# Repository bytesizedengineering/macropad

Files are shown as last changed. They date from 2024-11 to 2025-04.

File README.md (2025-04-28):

# Custom Macropad  

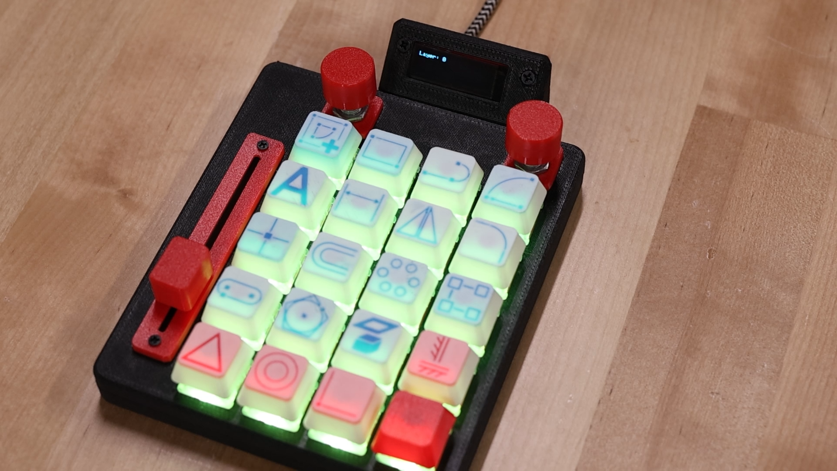
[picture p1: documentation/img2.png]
Project Image
  

## 🚀 Overview  
This project is a custom macropad featuring a 4x5 keyboard, 2 rotary encoders, a linear potentiometer, and an I2C display port. It was featured on the DigiKey [YouTube channel](https://www.youtube.com/@digikey) in [this video](#).  

## 📂 Repository Structure  
```
📁 mechanical_design/   # 3D models (Fusion 360, STLs, STEP files)
📁 electrical_design/   # KiCad PCB and schematic files
📁 firmware/            # Arduino, ESP, or other firmware code
📁 docs/                # PDFs, images, and additional documentation
```

## 🔩 Mechanical Design  
You can access the latest Fusion 360 model here:  
[🔗 View 3D Model in Fusion 360](https://a360.co/3RYLWHH)

## 🏗️ Build Instructions  

### 🖨️ 3D Printing  
- **Recommended Material**: [PLA/PETG/ABS]  
- **Layer Height**: [e.g., 0.2mm]  
- **Supports**: [Yes/No]  

### 🔌 Electronics  
- **Microcontroller**: [RP2040]  
- **Power Supply**: [USB C]  
- **PCB Fabrication**:  
  - Gerber files included in `electrical_design/`  

### 💾 Firmware Upload  
1. Connect XIAO RP2040 module to computer
2. Put into bootload mode
   While holding the boot button press reset.
   This should open up a removable storage window.   
3. Drag and drop the firmware to the removable storage window

## 🛒 Bill of Materials (BOM)
[DigiKey](https://www.digikey.com/en/mylists/list/9CPBP16BIQ)
| Part | Description | Purchase Link  |
|---|---|---|
| | | |

## 🎥 Video & More Info  
📺 Watch the full build video: [YouTube Video](#)  

## 📝 License  
This project is licensed under the **GNU General Public License v3.0**.  
You can read the full text in the [`LICENSE`](LICENSE) file or at [gnu.org](https://www.gnu.org/licenses/gpl-3.0.html).  

## ❤️ Support  
- Found this helpful? Consider supporting me on [Patreon](https://www.patreon.com/ByteSizedEngineering).  
- Follow me on [YouTube](https://www.youtube.com/@bytesizedengineering), [Instagram](https://www.instagram.com/bytesizedengineering/), and [GitHub](https://github.com/bytesizedengineering).

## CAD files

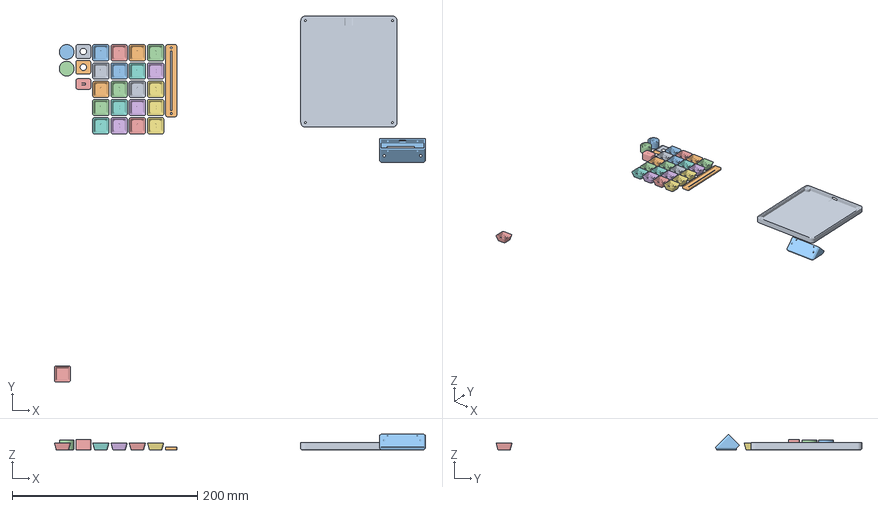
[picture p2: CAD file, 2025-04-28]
Mechanical Design/v1.0/project file.3mf
400.8 x 395.0 x 17.0 mm
bottom
slider_cover
OLED case
xda_key x 20
Create Sketch
encoder_cover x 2
knob x 2
slider_knob

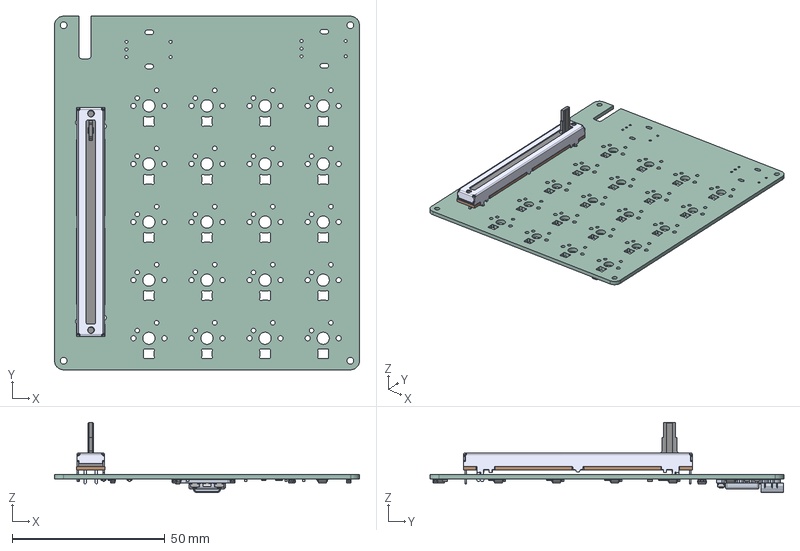
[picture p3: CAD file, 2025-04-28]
Electrical Design/macropad/macropad.step
100.0 x 116.0 x 23.1 mm
60310CI
R_0603_1608Metric x 17
C_0603_1608Metric x 25
D_SOD_123 x 22
SOT_23_5
Seeed Studio XIAO RP2040 v26
macropad_PCB

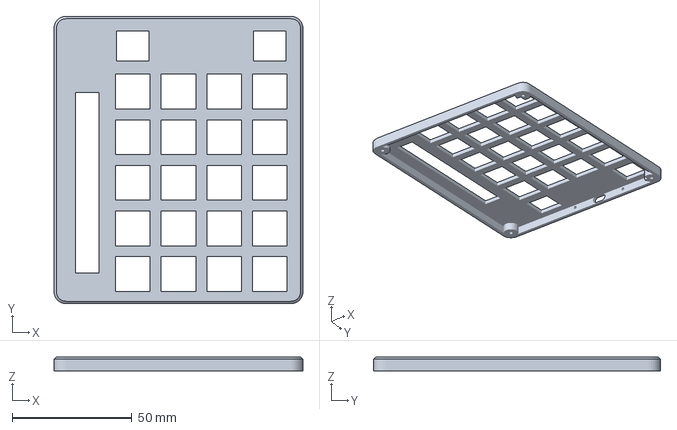
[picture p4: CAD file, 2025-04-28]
Mechanical Design/v1.0/top.3mf
104.0 x 120.0 x 6.00 mm

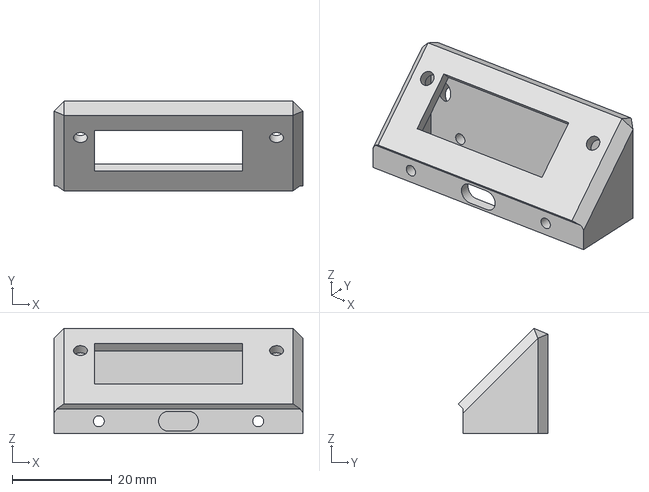
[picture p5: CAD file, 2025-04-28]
Mechanical Design/v1.0/OLED case.3mf
50.0 x 18.0 x 21.2 mm

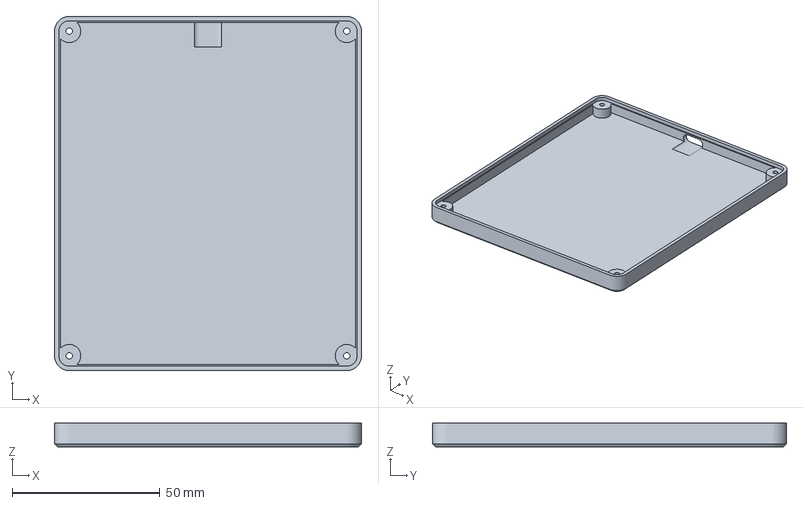
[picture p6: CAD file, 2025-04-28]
Mechanical Design/v1.0/bottom.3mf
104.0 x 120.0 x 8.00 mm

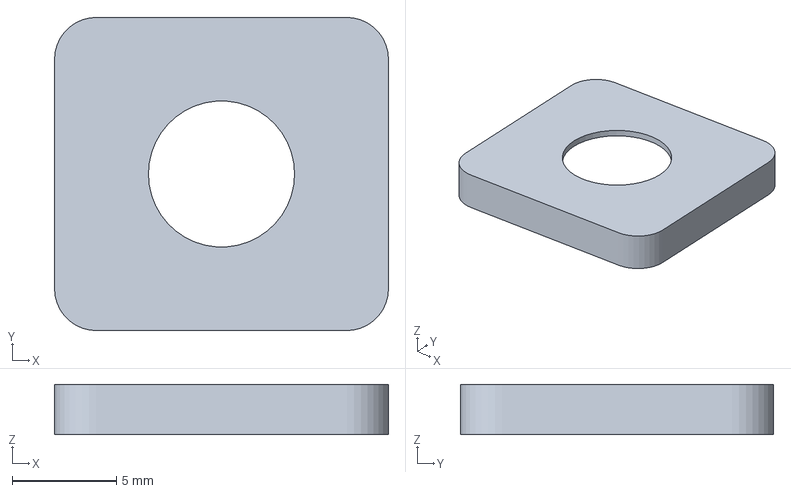
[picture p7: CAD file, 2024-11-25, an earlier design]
Mechanical Design/v0.1/encoder_cover.3MF
16.0 x 15.0 x 2.40 mm

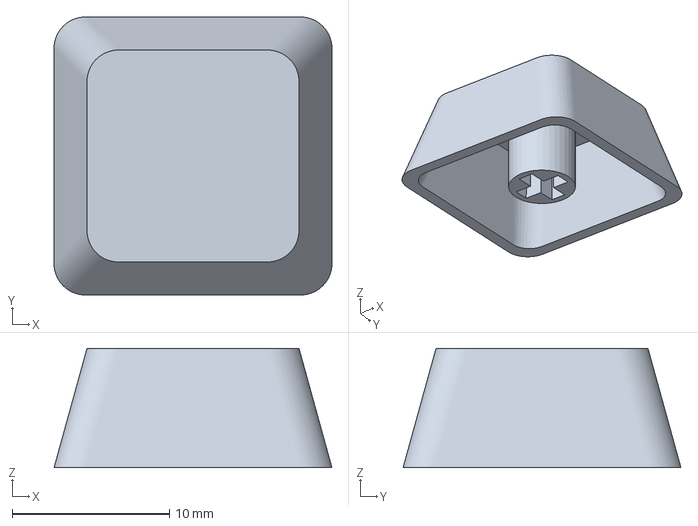
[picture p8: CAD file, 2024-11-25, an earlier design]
Mechanical Design/v0.1/xda_key.3MF
17.7 x 17.7 x 7.61 mm

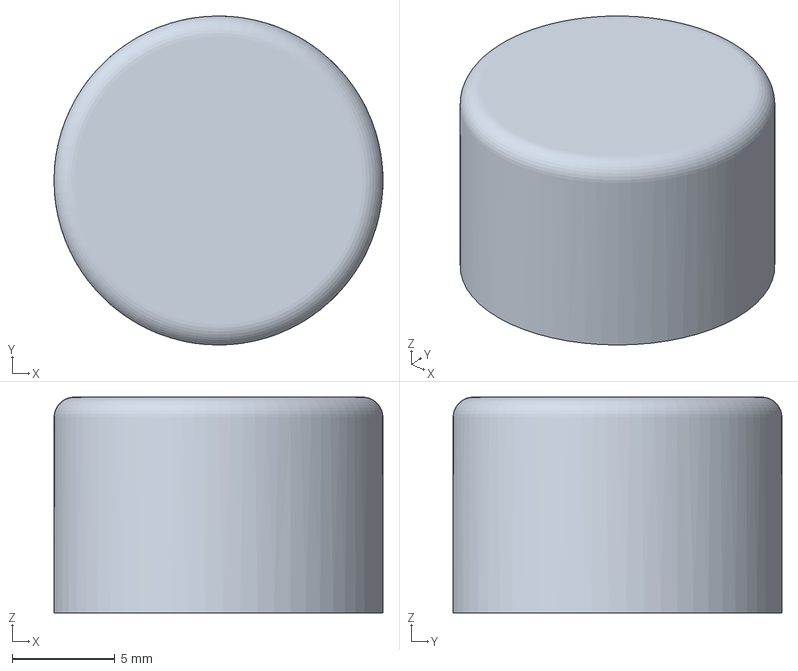
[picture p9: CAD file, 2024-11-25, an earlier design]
Mechanical Design/v0.1/knob.3MF
16.0 x 16.0 x 10.5 mm

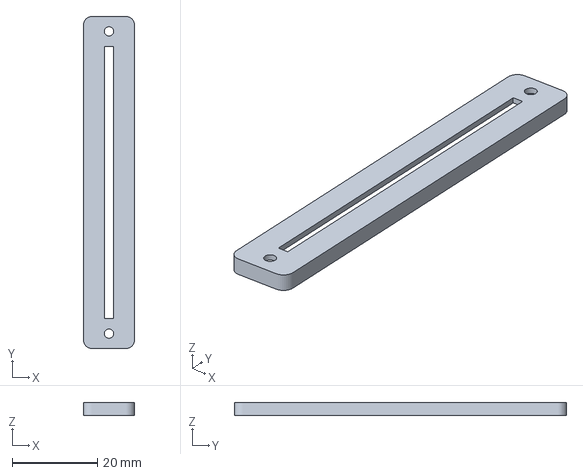
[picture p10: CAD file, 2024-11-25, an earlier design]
Mechanical Design/v0.1/slider_cover.3MF
12.0 x 78.0 x 3.00 mm

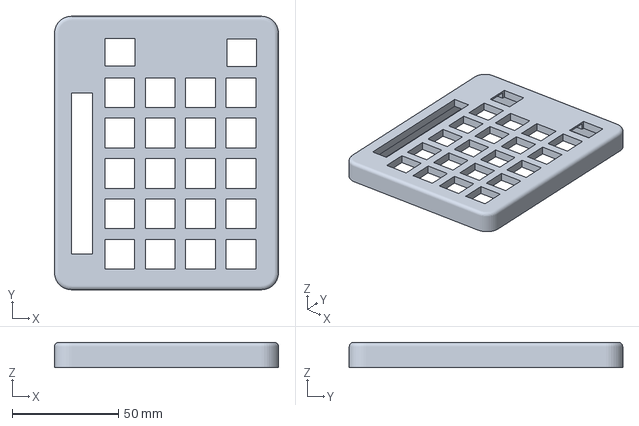
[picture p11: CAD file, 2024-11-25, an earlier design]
Mechanical Design/v0.1/case.3MF
105.6 x 129.0 x 12.0 mm

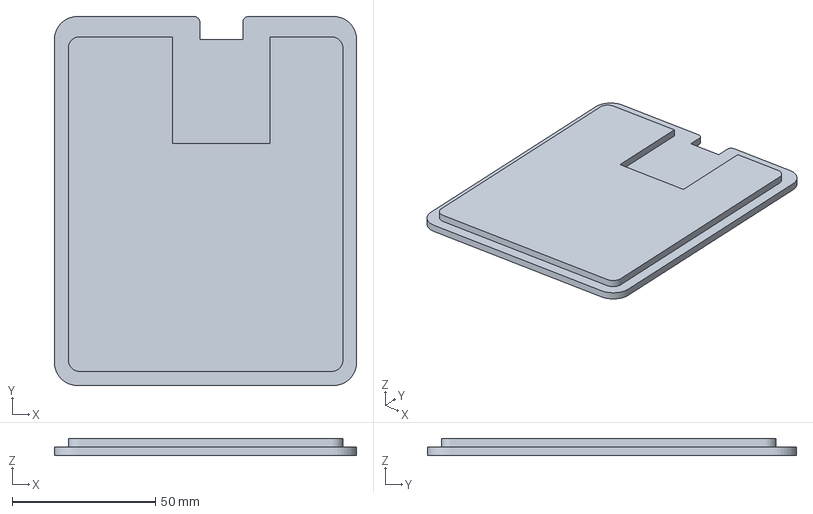
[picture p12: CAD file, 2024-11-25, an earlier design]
Mechanical Design/v0.1/bottom.3MF
105.6 x 129.0 x 6.00 mm

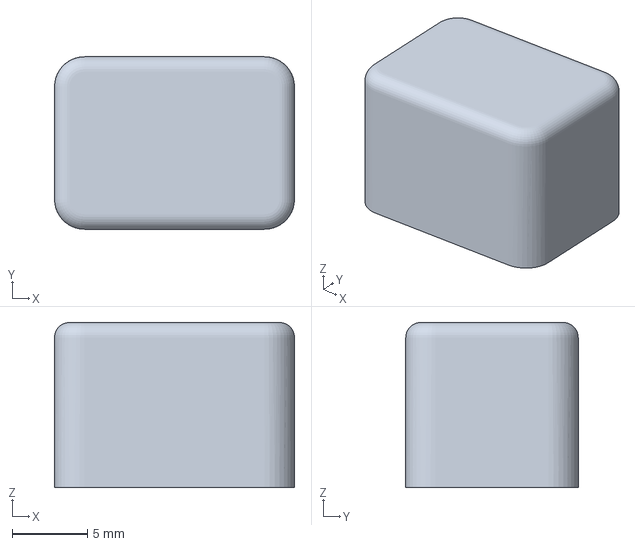
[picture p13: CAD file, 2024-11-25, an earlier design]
Mechanical Design/v0.1/slider_knob.3MF
16.0 x 11.5 x 11.0 mm

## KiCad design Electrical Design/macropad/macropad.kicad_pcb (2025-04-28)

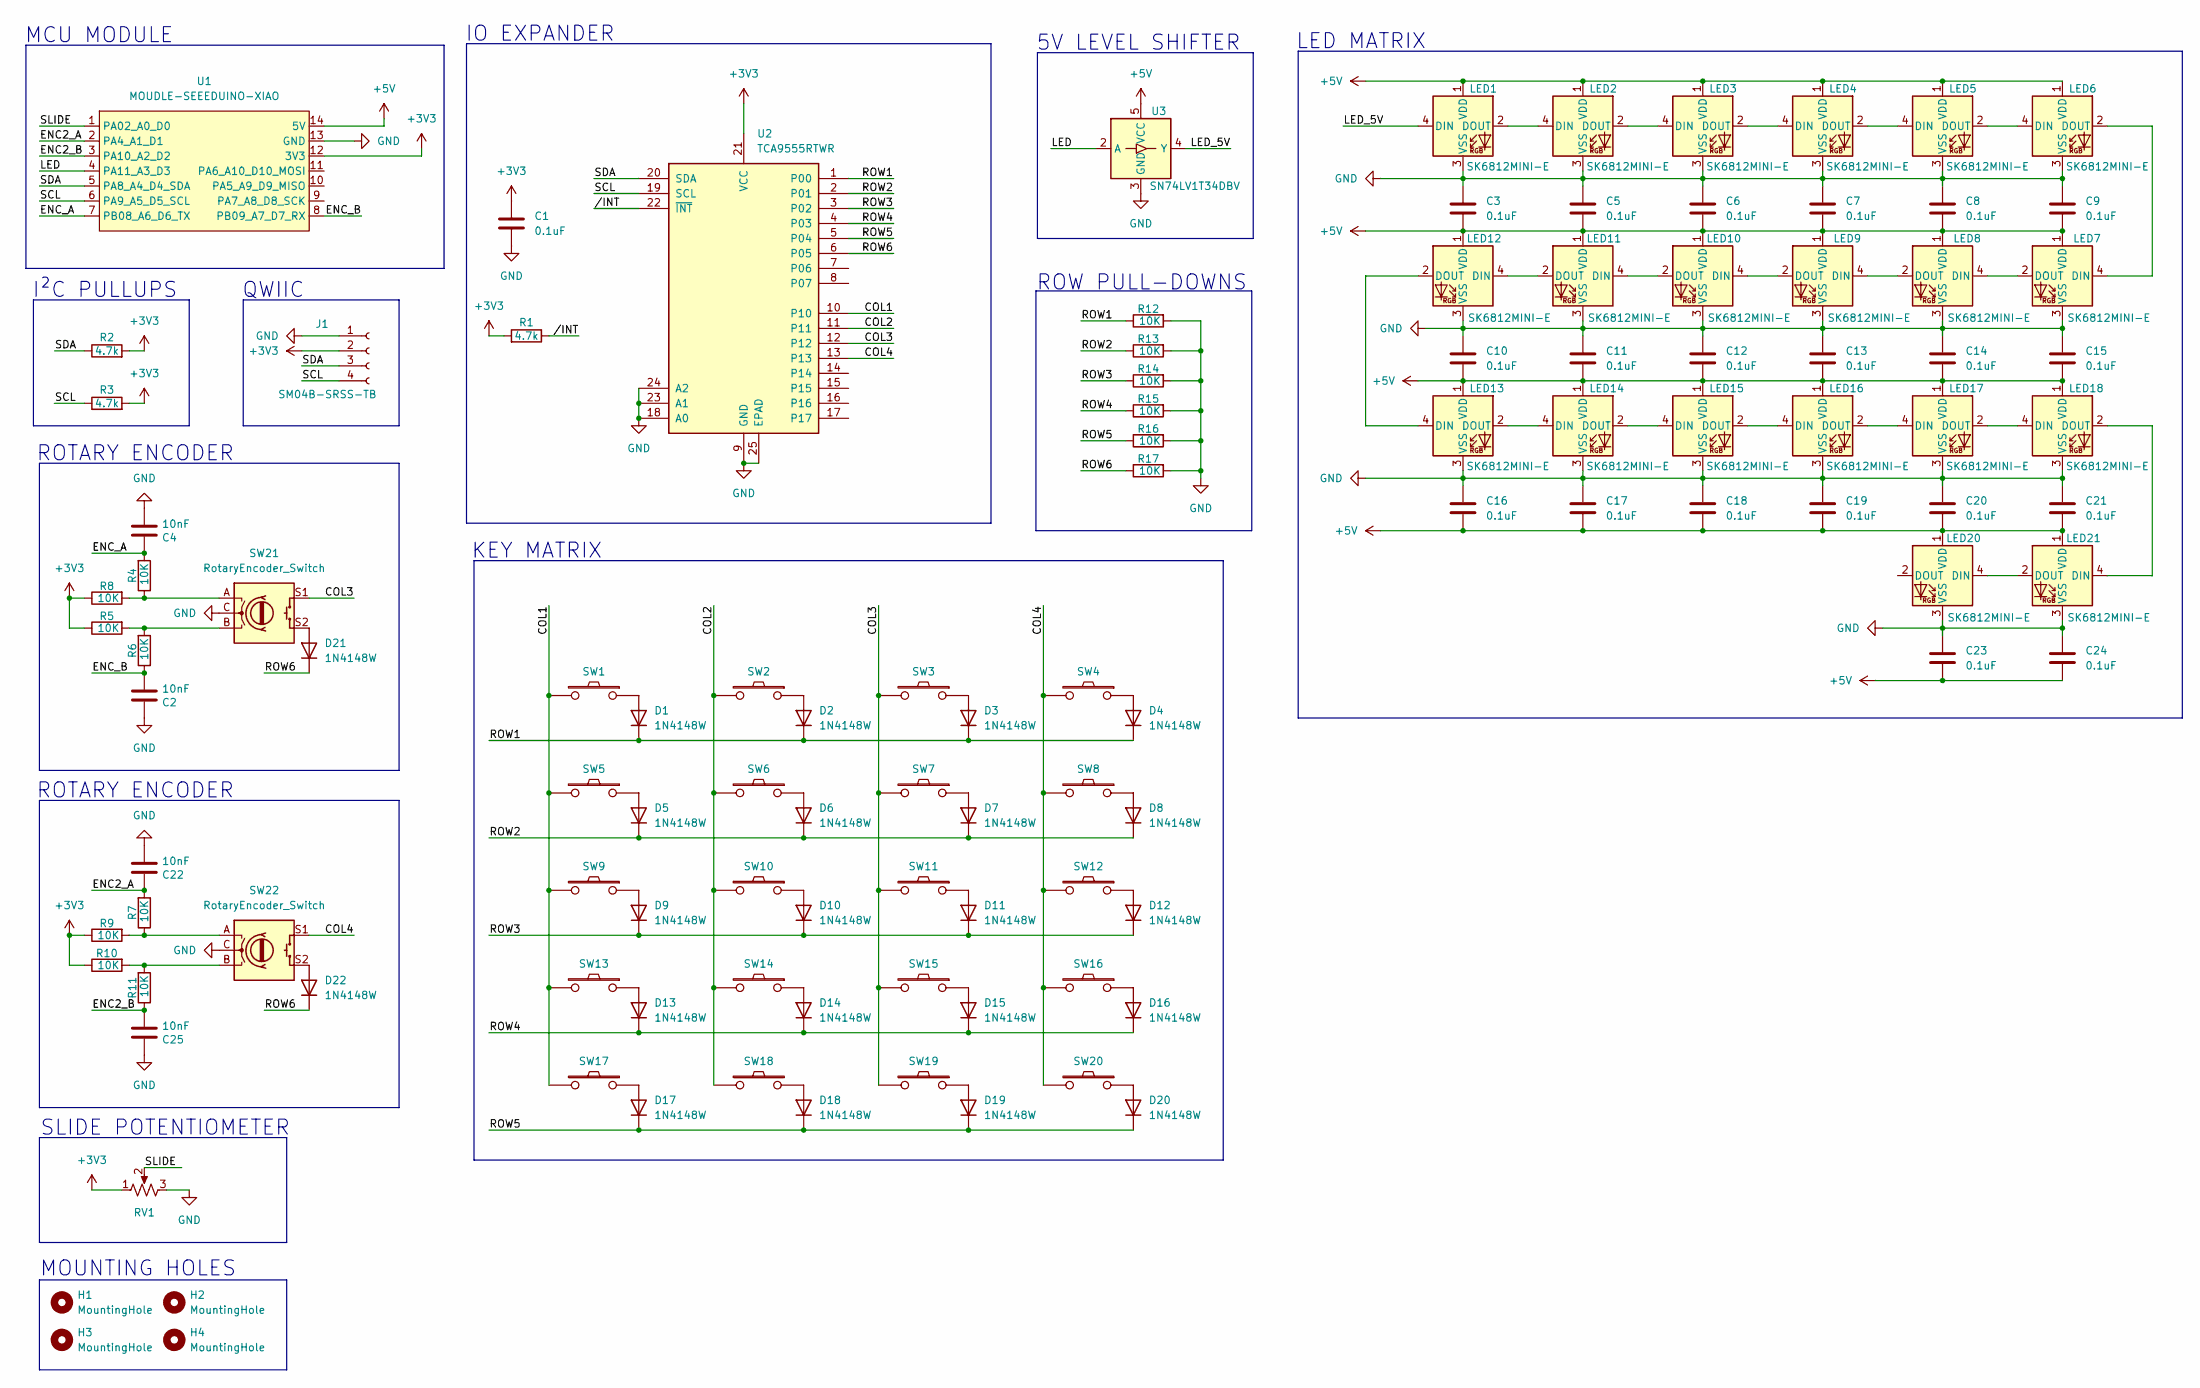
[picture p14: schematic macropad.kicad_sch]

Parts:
C1, C3, C5, C6, C7, C8, C9, C10, C11, C12, C13, C14, C15, C16, C17, C18, C19, C20, C21, C23, C24: 0.1uF; C_0603_1608Metric_Pad1.08x0.95mm_HandSolder; DigiKey Part Number CC0603KRX7R7BB104
C2, C4, C22, C25: 10nF; C_0603_1608Metric_Pad1.08x0.95mm_HandSolder; DigiKey Part Number C1608X7R2A103M080AA
D1, D2, D3, D4, D5, D6, D7, D8, D9, D10, D11, D12, D13, D14, D15, D16, D17, D18, D19, D20, D21, D22: 1N4148W; D_SOD-123; DigiKey Part Number 1N4148W
H1, H2, H3, H4: MountingHole; MountingHole_2.2mm_M2
J1: SM04B-SRSS-TB; CONN_SM04B-SRSS-TB_JST; DigiKey Part Number SM04B-SRSS-TB
LED1, LED2, LED3, LED4, LED5, LED6, LED7, LED8, LED9, LED10, LED11, LED12, LED13, LED14, LED15, LED16, LED17, LED18, LED20, LED21: SK6812MINI-E; MX_SK6812MINI-E; DigiKey Part Number 1528-4960-ND
R1, R2, R3: 4.7k; R_0603_1608Metric_Pad0.98x0.95mm_HandSolder; DigiKey Part Number RMCF0603FT4K70
R4, R5, R6, R7, R8, R9, R10, R11, R12, R13, R14, R15, R16, R17: 10K; R_0603_1608Metric_Pad0.98x0.95mm_HandSolder; DigiKey Part Number RMCF0603FT10K0
RV1: R_Potentiometer_US; PTA6043-2010CIB103; DigiKey Part Number PTA6043-2010CIB103
SW1, SW2, SW3, SW4, SW5, SW6, SW7, SW8, SW9, SW10, SW11, SW12, SW13, SW14, SW15, SW16, SW17, SW18, SW19, SW20: keyswitch; SW_Cherry_MX_1.00u_PCB; DigiKey Part Number MX2A-11NA
SW21, SW22: RotaryEncoder_Switch; RotaryEncoder_Alps_EC11E-Switch_Vertical_H20mm; DigiKey Part Number PEC11L-4115F-S0020
U1: MOUDLE-SEEEDUINO-XIAO; MOUDLE14P-SMD-2.54-21X17.8MM; DigiKey Part Number 1597-102010428-ND
U2: TCA9555RTWR; WQFN-24-1EP_4x4mm_P0.5mm_EP2.45x2.45mm; DigiKey Part Number TCA9555RTWR
U3: SN74LV1T34DBV; SOT-23-5; DigiKey Part Number SN74LV1T34DBV

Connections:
+3V3: C1.1, J1.2, R1.2, R2.2, R3.2, R5.1, R8.1, R9.1, R10.1, RV1.1, U1.12 (3V3), U2.21 (VCC)
+5V: C3.2, C5.2, C6.2, C7.2, C8.2, C9.2, C10.2, C11.2, C12.2, C13.2, C14.2, C15.2, C16.2, C17.2, C18.2, C19.2, C20.2, C21.2, C23.2, C24.2, LED1.1 (VDD), LED2.1 (VDD), LED3.1 (VDD), LED4.1 (VDD), LED5.1 (VDD), LED6.1 (VDD), LED7.1 (VDD), LED8.1 (VDD), LED9.1 (VDD), LED10.1 (VDD), LED11.1 (VDD), LED12.1 (VDD), LED13.1 (VDD), LED14.1 (VDD), LED15.1 (VDD), LED16.1 (VDD), LED17.1 (VDD), LED18.1 (VDD), LED20.1 (VDD), LED21.1 (VDD), U1.14 (5V), U3.5 (VCC)
/COL1: SW1.2, SW5.2, SW9.2, SW13.2, SW17.2, U2.10
/COL2: SW2.2, SW6.2, SW10.2, SW14.2, SW18.2, U2.11
/COL3: SW3.2, SW7.2, SW11.2, SW15.2, SW19.2, SW21.S1, U2.12
/COL4: SW4.2, SW8.2, SW12.2, SW16.2, SW20.2, SW22.S1, U2.13
/ENC2_A: C22.2, R7.2, U1.2 (PA4_A1_D1)
/ENC2_B: C25.1, R11.1, U1.3 (PA10_A2_D2)
/ENC_A: C4.2, R4.2, U1.7 (PB08_A6_D6_TX)
/ENC_B: C2.1, R6.1, U1.8 (PB09_A7_D7_RX)
/LED: U1.4 (PA11_A3_D3), U3.2 (A)
/LED_5V: LED1.4 (DIN), U3.4 (Y)
/ROW1: D1.1 (K), D2.1 (K), D3.1 (K), D4.1 (K), R12.1, U2.1 (P00)
/ROW2: D5.1 (K), D6.1 (K), D7.1 (K), D8.1 (K), R13.1, U2.2 (P01)
/ROW3: D9.1 (K), D10.1 (K), D11.1 (K), D12.1 (K), R14.1, U2.3 (P02)
/ROW4: D13.1 (K), D14.1 (K), D15.1 (K), D16.1 (K), R15.1, U2.4 (P03)
/ROW5: D17.1 (K), D18.1 (K), D19.1 (K), D20.1 (K), R16.1, U2.5 (P04)
/ROW6: D21.1 (K), D22.1 (K), R17.1, U2.6 (P05)
/SCL: J1.4, R3.1, U1.6 (PA9_A5_D5_SCL), U2.19 (SCL)
/SDA: J1.3, R2.1, U1.5 (PA8_A4_D4_SDA), U2.20 (SDA)
/SLIDE: RV1.2, U1.1 (PA02_A0_D0)
//INT: R1.1, U2.22 (~INT)
GND: C1.2, C2.2, C3.1, C4.1, C5.1, C6.1, C7.1, C8.1, C9.1, C10.1, C11.1, C12.1, C13.1, C14.1, C15.1, C16.1, C17.1, C18.1, C19.1, C20.1, C21.1, C22.1, C23.1, C24.1, C25.2, J1.1, LED1.3 (VSS), LED2.3 (VSS), LED3.3 (VSS), LED4.3 (VSS), LED5.3 (VSS), LED6.3 (VSS), LED7.3 (VSS), LED8.3 (VSS), LED9.3 (VSS), LED10.3 (VSS), LED11.3 (VSS), LED12.3 (VSS), LED13.3 (VSS), LED14.3 (VSS), LED15.3 (VSS), LED16.3 (VSS), LED17.3 (VSS), LED18.3 (VSS), LED20.3 (VSS), LED21.3 (VSS), R12.2, R13.2, R14.2, R15.2, R16.2, R17.2, RV1.3, SW21.C, SW22.C, U1.13 (GND), U2.9 (GND), U2.18 (A0), U2.23 (A1), U2.24 (A2), U2.25 (EPAD), U3.3 (GND)
unnamed: D1.2 (A), SW1.1
unnamed: D2.2 (A), SW2.1
unnamed: D3.2 (A), SW3.1
unnamed: D4.2 (A), SW4.1
unnamed: D5.2 (A), SW5.1
unnamed: D6.2 (A), SW6.1
unnamed: D7.2 (A), SW7.1
unnamed: D8.2 (A), SW8.1
unnamed: D9.2 (A), SW9.1
unnamed: D10.2 (A), SW10.1
unnamed: D11.2 (A), SW11.1
unnamed: D12.2 (A), SW12.1
unnamed: D13.2 (A), SW13.1
unnamed: D14.2 (A), SW14.1
unnamed: D15.2 (A), SW15.1
unnamed: D16.2 (A), SW16.1
unnamed: D17.2 (A), SW17.1
unnamed: D18.2 (A), SW18.1
unnamed: D19.2 (A), SW19.1
unnamed: D20.2 (A), SW20.1
unnamed: D21.2 (A), SW21.S2
unnamed: D22.2 (A), SW22.S2
unnamed: LED1.2 (DOUT), LED2.4 (DIN)
unnamed: LED2.2 (DOUT), LED3.4 (DIN)
unnamed: LED3.2 (DOUT), LED4.4 (DIN)
unnamed: LED4.2 (DOUT), LED5.4 (DIN)
unnamed: LED5.2 (DOUT), LED6.4 (DIN)
unnamed: LED6.2 (DOUT), LED7.4 (DIN)
unnamed: LED7.2 (DOUT), LED8.4 (DIN)
unnamed: LED8.2 (DOUT), LED9.4 (DIN)
unnamed: LED9.2 (DOUT), LED10.4 (DIN)
unnamed: LED10.2 (DOUT), LED11.4 (DIN)
unnamed: LED11.2 (DOUT), LED12.4 (DIN)
unnamed: LED12.2 (DOUT), LED13.4 (DIN)
unnamed: LED13.2 (DOUT), LED14.4 (DIN)
unnamed: LED14.2 (DOUT), LED15.4 (DIN)
unnamed: LED15.2 (DOUT), LED16.4 (DIN)
unnamed: LED16.2 (DOUT), LED17.4 (DIN)
unnamed: LED17.2 (DOUT), LED18.4 (DIN)
unnamed: LED18.2 (DOUT), LED21.4 (DIN)
unnamed: LED20.4 (DIN), LED21.2 (DOUT)
unnamed: R4.1, R8.2, SW21.A
unnamed: R5.2, R6.2, SW21.B
unnamed: R7.1, R9.2, SW22.A
unnamed: R10.2, R11.2, SW22.B

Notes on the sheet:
LED MATRIX
ROW PULL-DOWNS
MCU MODULE
IO EXPANDER
SLIDE POTENTIOMETER
KEY MATRIX
MOUNTING HOLES
QWIIC
ROTARY ENCODER
5V LEVEL SHIFTER
I²C PULLUPS

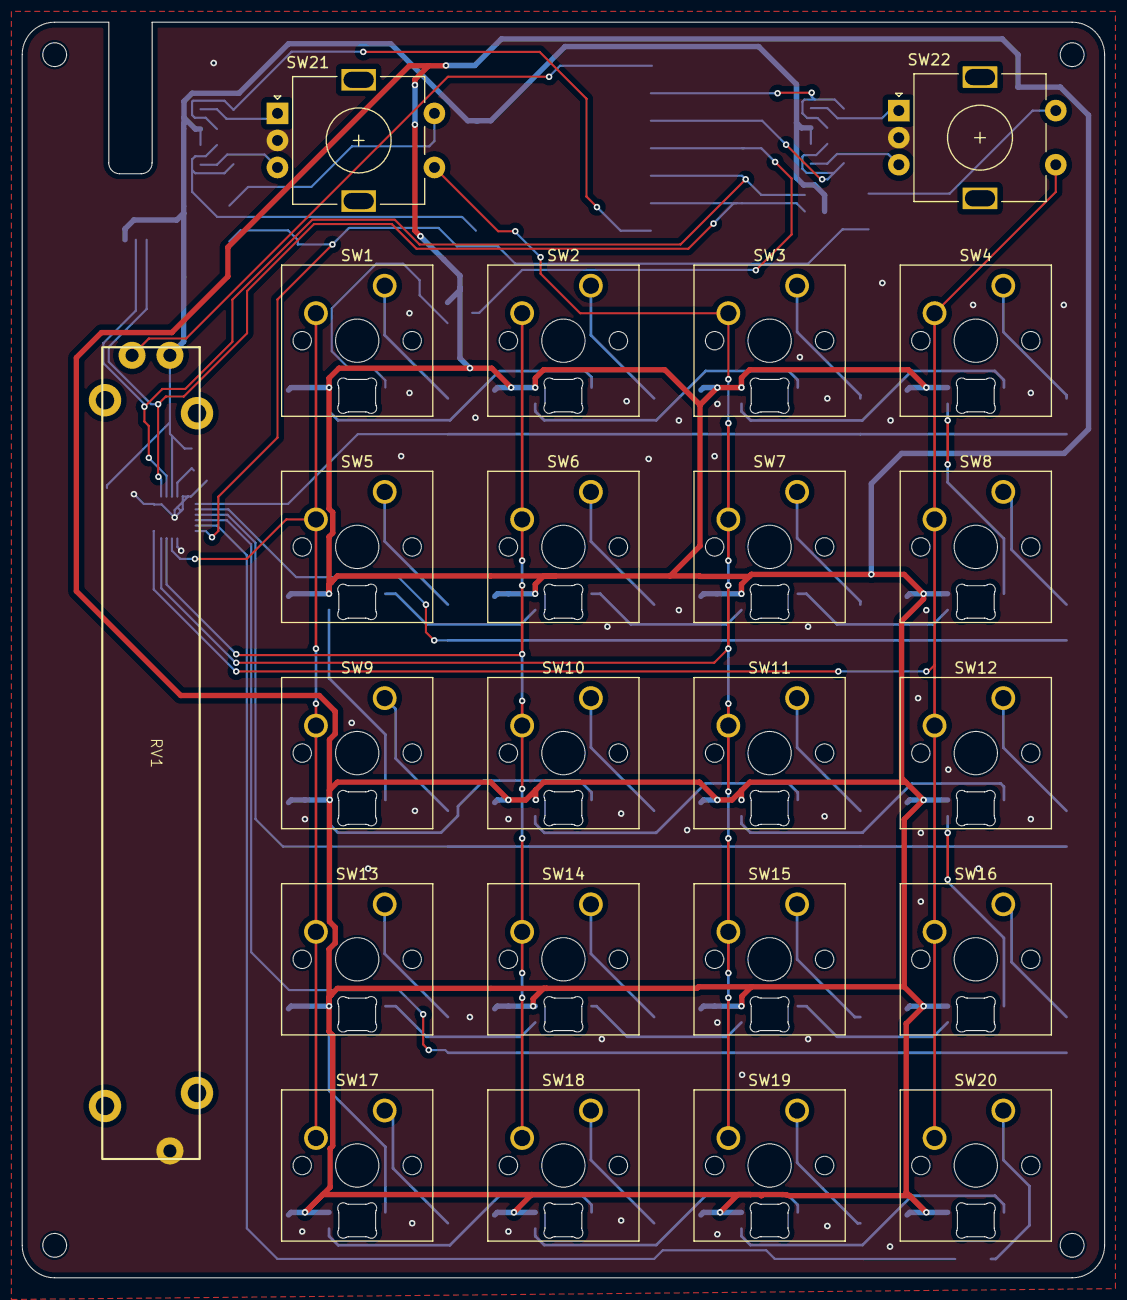
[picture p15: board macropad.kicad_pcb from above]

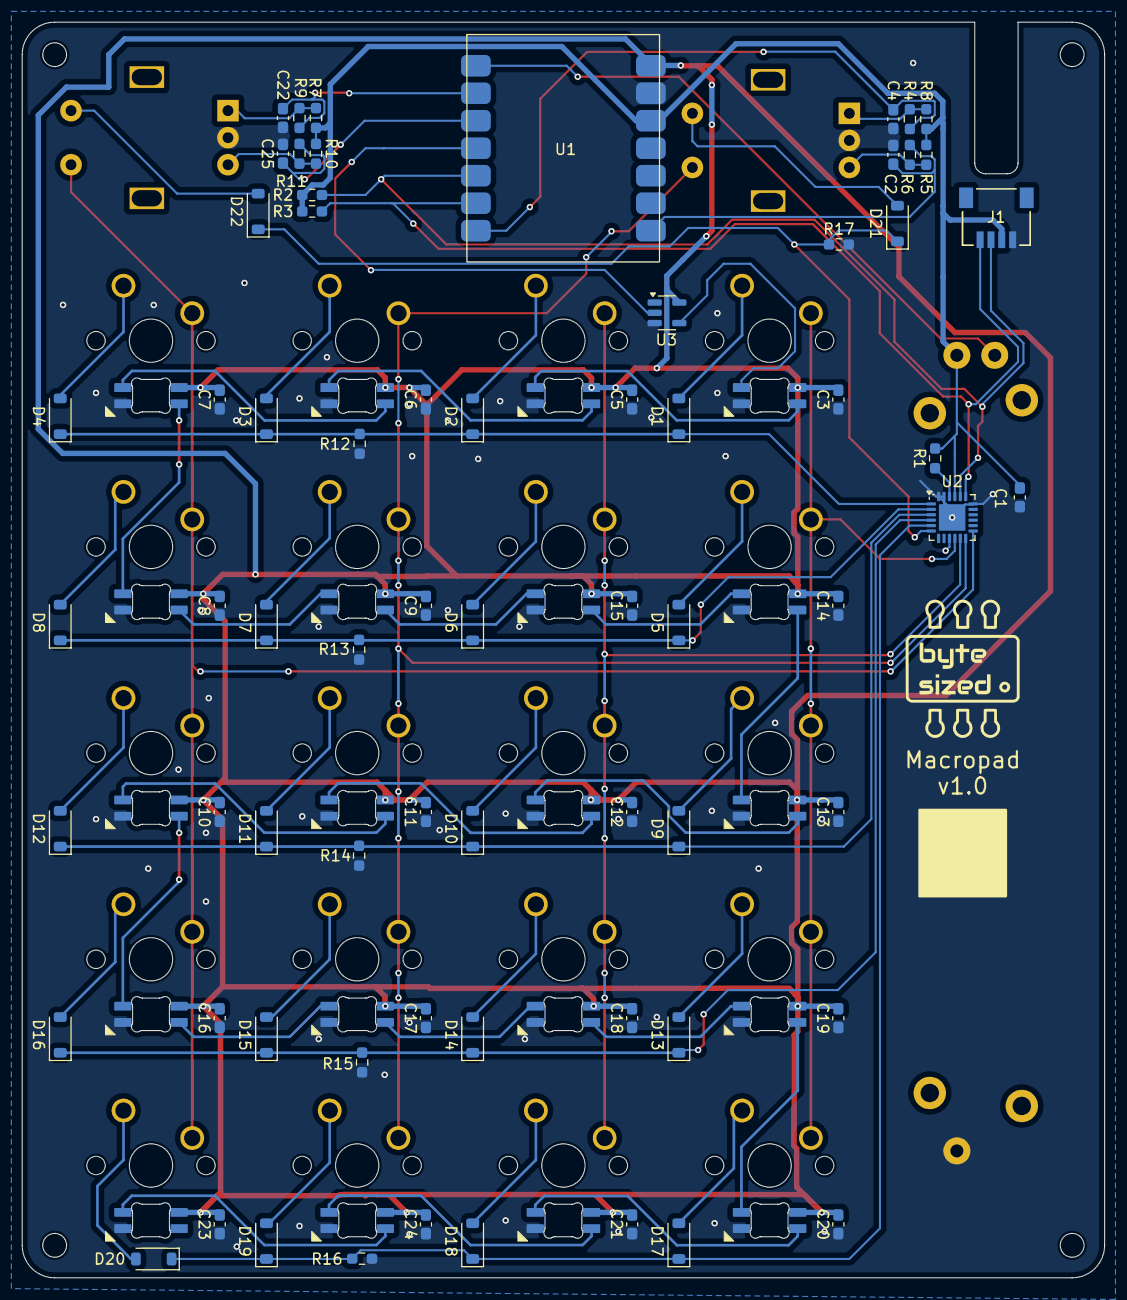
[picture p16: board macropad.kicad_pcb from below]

Board: 2 copper layers, 100.0 x 116.0 mm, 115 parts (68 on the bottom side), 68 nets.

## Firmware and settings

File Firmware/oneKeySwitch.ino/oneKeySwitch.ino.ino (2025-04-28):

#include <Adafruit_TinyUSB.h>

// Define the button pin
#define BUTTON_PIN 2

// Track the button state
bool buttonState = false;
bool lastButtonState = false;

void setup() {
  pinMode(BUTTON_PIN, INPUT_PULLUP);  // Internal pull-up resistor
  TinyUSBDevice.begin();  // Start TinyUSB
  delay(1000);  // Allow some startup time
}

void loop() {
  // Read the current state of the button
  buttonState = digitalRead(BUTTON_PIN);

  // Detect a button press (transition from HIGH to LOW)
  if (buttonState == LOW && lastButtonState == HIGH) {
    sendKeyPress();
  }

  // Update the last state
  lastButtonState = buttonState;

  delay(10);  // Debounce delay
}

void sendKeyPress() {
  // Send the letter 'a' to the computer
  TinyUSBKeyboard.print("a");
}

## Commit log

2024-11-25 Created repo and created design folders
    [bottom.3MF, case.3MF, encoder_cover.3MF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]
2024-11-25 Centered XIAO RP2040 and moved around some footprints to accommodate its new placement.
    [macropad.kicad_pcb]
2024-11-26 reduced the width of the I2C cutout
    [macropad.kicad_pcb]
2025-04-28 updated design
    [OLED case.3mf, bottom.3MF, bottom.3mf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]
